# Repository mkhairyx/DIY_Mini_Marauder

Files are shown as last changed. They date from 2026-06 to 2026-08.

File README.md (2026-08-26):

# DIY_Mini_Marauder

This is an open source version of [JustCallMeKoko's](github.com/justcallmekoko) marauder mini with better documentation and tutorials on how flash the device after making it. <br>
<br>

The reason I made this repository is becaused I have always wanted to have my own marauder mini but it was unavailble and there was no Schematics to be found for it. <br>
Only thing I was able to find was the PCB and the Case for it. I reverse engineered the PCB to have a useful schematic that anyone can use to make their own PCB and maybe make changes to it. <br>

## The Poster
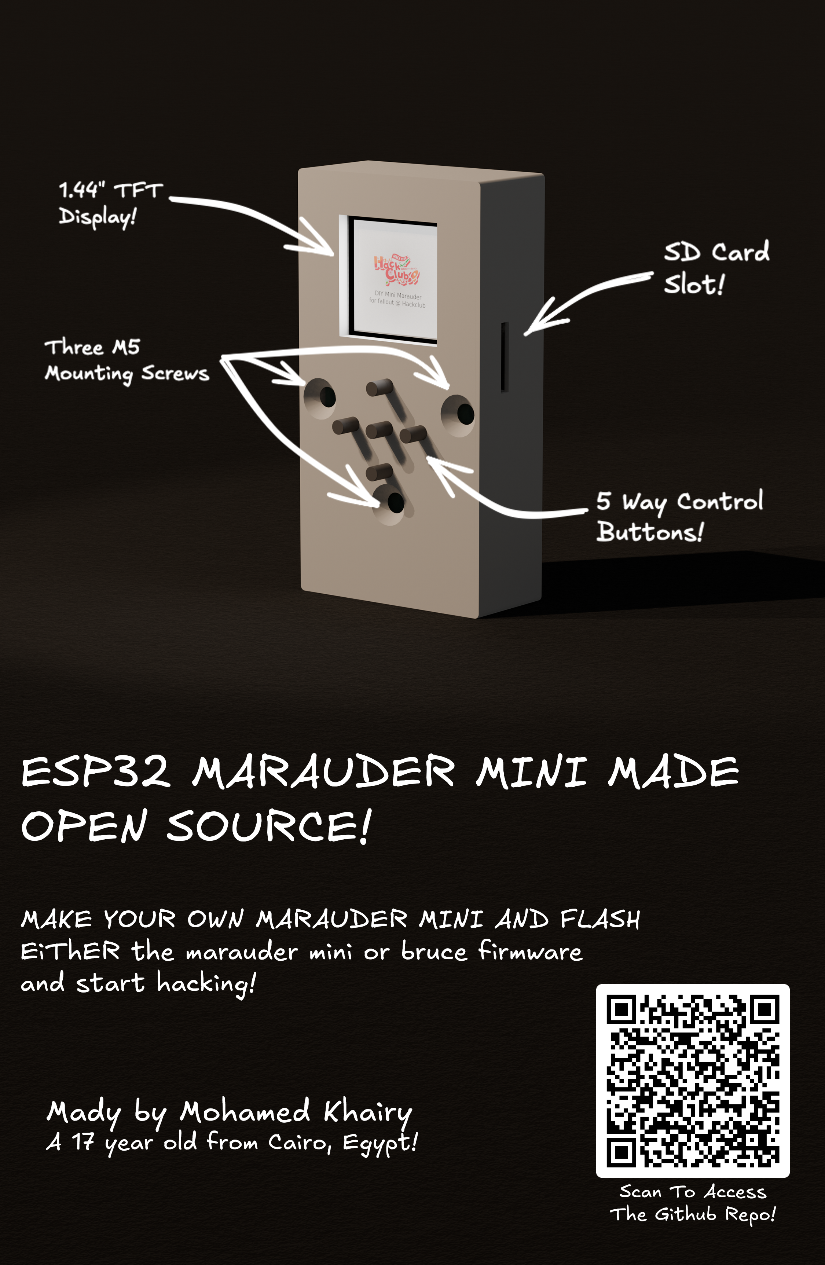
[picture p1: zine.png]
Poster


## The Design
### The PCB
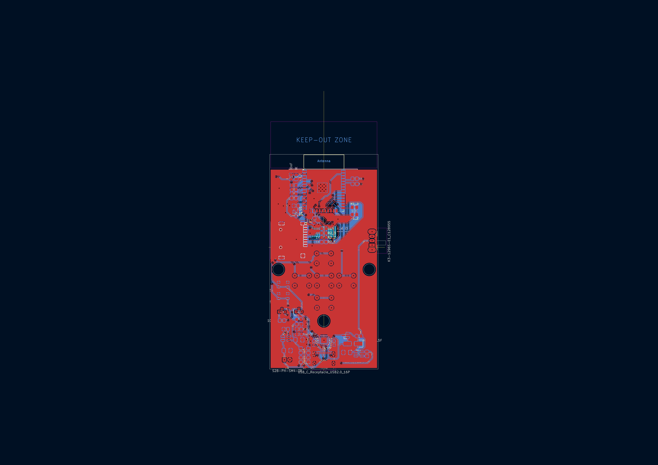
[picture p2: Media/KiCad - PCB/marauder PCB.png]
PCB

### The Schematics
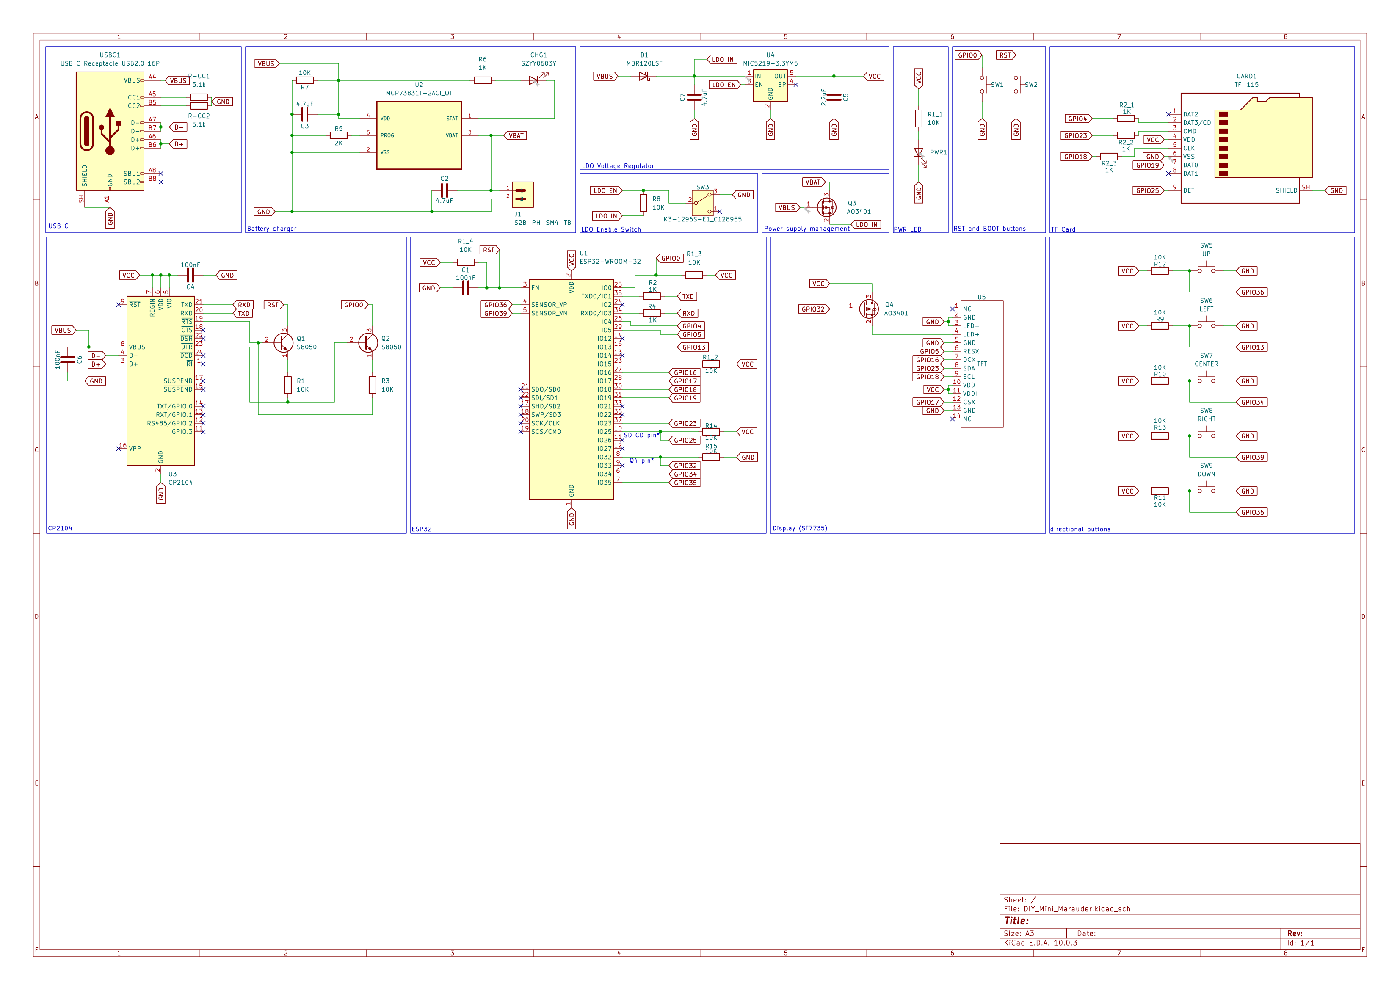
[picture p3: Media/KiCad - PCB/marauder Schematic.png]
Schematics

### The Enclosure Case 
With the device inside:
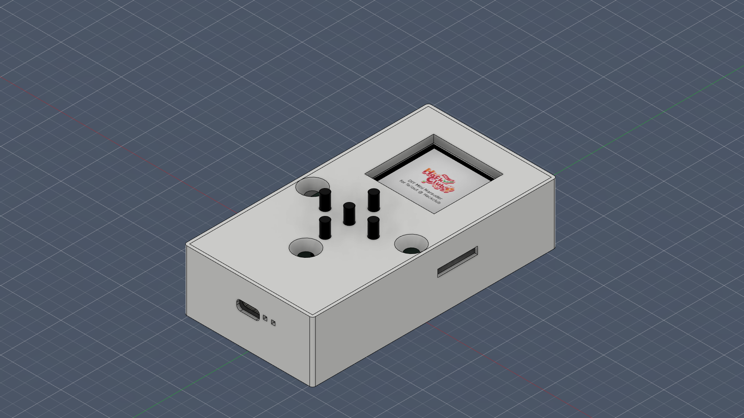
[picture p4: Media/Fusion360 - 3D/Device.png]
Device


Without the device inside:
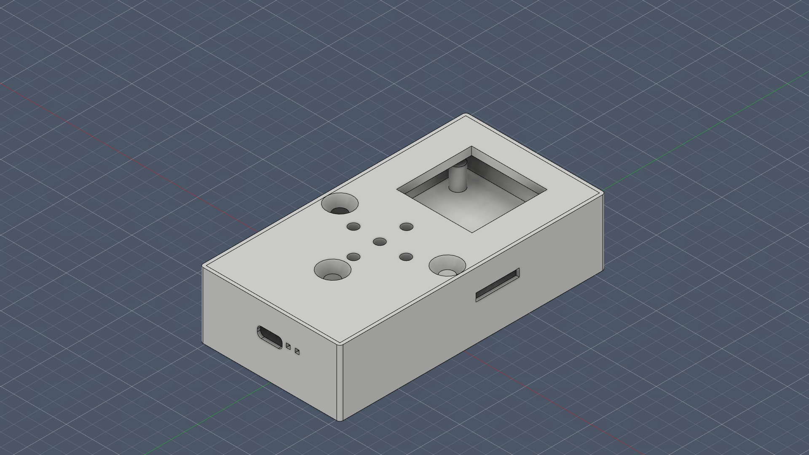
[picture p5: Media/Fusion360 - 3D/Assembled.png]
Assmebled


## Assembly
### Step Files
All of the step files can be downloaded [here](./Step_Files/).

### Disassembly video

https://github.com/user-attachments/assets/7e853b93-fa27-431c-8479-e6c7b8179391

## Firmware
### Fzee flasher (Marauder Mini)
- Visit the [FZEE FLASHER](https://fzeeflasher.com/) website
- Make sure your device is connected to your PC
- Click "Connect" <br>


- Select the Programmer chip for your device (which would be CP2104 if you used the schematics/PCB in this repository) <br>


- If you used the schematics/PCB provided in this repository, then you can skip this step. <br>
As soon as you see this screen, hold down the BOOT button on your device as the flasher will automatically reset the device and it will go into the boatloader mode <br>


- Select "ESP32 Marauder Mini Device" <br>


- Select the latest version <br>


- Select "Marauder" as the firmware <br>


- Erase the device first to make sure that it's not affected by any previously installed firmwares <br>


- Click "Program" <br>


- It will take arround 10 seconds to flash the firmware.  <br>
  After those 10 seconds, you should see this screen which indicates that you succesfully flashed the device with the new firmware: <br>
  

### Bruce (Bruce's Firmware)
- Visit [Bruce's Web Firmware Flasher](https://bruce.computer/flasher) 
- Select whatever release you want (it's recommended to select the latest release)
 
 
- Select "Custom Boards"


- Select "Marauder Mini"


- Select "Connect to Device"


- Select the Programmer chip for your device (which would be CP2104 if you used the schematics/PCB in this repository)


- Select "Instal Marauder-Mini"


- Then make sure to have the "Erase device" option enabled then click next


- Confirm the instalation


- If you used the schematics/PCB provided in this repository, then you can skip this step. <br>
As soon as you see this screen, make sure to put your device into the bootloader mode by holding the BOOT button down, pressing the RST button, and then after 2 seconds release the BOOT button.


- It will take around 2 minutes to upload the firmware. <br>
After those 2 minutes, you should see this screen which indicates that you had a succesful instalation:


## Buttons and leds
### The two LEDs
Next to the USB-C port there are 2 LEDs: <br>
- The white one indicates wether the device is powered or not. <br>
- The blue one indicates wether the device is recieved power from the USB-C port or not (which is used to charge the battery).

### The two buttons on the back of the device and their functions
- The Upper button is used to put the ESP32 into the bootloader mode (AKA. the BOOT button). <br>
- The lower button is used to reset the device (AKA. the RST button).<br>

### The side switch
- The side switch is used to power the device ON or OFF.

## BOM
### BOM table (components only)
|Name |Value |Link |Cost (EGP) per one|Cost (USD)|Total Cost (EGP) |Total Cost (USD)|Qty of packages|Description |quantiy per pack|
|---|---|---|---|---|---|---|---|---|---|
|Capacitor |100nF |https://lampatronics.com/product/smd-multilayer-ceramic-capacitor-0805-2012-104-100nf-50v-1pcs-2 | EGP 1.00 | $0.02 | EGP 3.00 | $0.06 |3 | |1 |
|Capacitor |4.7uF |https://lampatronics.com/product/smd-multilayer-ceramic-capacitor-1206-4-7uf-16v-1pcs | EGP 1.50 | $0.03 | EGP 4.50 | $0.09 |3 | |1 |
|Capacitor |2.2uF |https://lampatronics.com/product/smd-multilayer-ceramic-capacitor-0805-2-2uf-50v-1pcs | EGP 1.00 | $0.02 | EGP 1.00 | $0.02 |1 | |1 |
|SD Card slot |TF-115 |https://lampatronics.com/product/push-push-type-tf-micro-sd-card-socket-adapter-automatic-pcb-connector | EGP 8.00 | $0.15 | EGP 8.00 | $0.15 |1 | |1 |
|Charging LED |SZYY0603Y |https://lampatronics.com/product/smd-led-0805-blue-10pcs | EGP 8.00 | $0.15 | EGP 8.00 | $0.15 |1 |Charge LED (RED) |10 |
|Power LED |SZYY0603Y |https://lampatronics.com/product/smd-led-0805-white-10pcs | EGP 8.00 | $0.15 | EGP 8.00 | $0.15 |1 |Power LED (White) |10 |
|Schottky Diode |MBR120LSF (alt: 1N5819 SS14)|https://uge-one.com/product/smd-schottky-diode-1n5819-ss14-1a-40v-sma-package/ | EGP 2.50 | $0.05 | EGP 2.50 | $0.05 |1 |Schottky |1 |
|JST Connector |S2B-PH-SM4-TB |https://uge-one.com/product/jst-connector-male-polarized-xh2-54-2p/ | EGP 1.14 | $0.02 | EGP 1.14 | $0.02 |1 |JST connector |1 |
|BOOT and RESET transistors |S8050 |https://lampatronics.com/product/s8050-transistor-40v-0-5a-npn | EGP 0.50 | $0.01 | EGP 1.00 | $0.02 |2 |RST&BOOT transistors |1 |
|Power management and TFT LED PWM|AO3401 |https://uge-one.com/product/ao3401-sot23-general-purpose-p-channel-mosfet-smd-transistor-sot-23/ | EGP 3.00 | $0.06 | EGP 6.00 | $0.12 |2 |Power manage, TFT LED|1 |
|Resistor |5.1k |https://uge-one.com/product/smd-chip-resistor-size-0603-5-1k-ohm/ | EGP 0.50 | $0.01 | EGP 1.00 | $0.02 |2 |USB-C resistors 5.1k |1 |
|Resistor |10K |https://lampatronics.com/product/smd-resistor-10kohm-103-0805-10pcs | EGP 2.00 | $0.04 | EGP 4.00 | $0.08 |2 | |10 |
|Resistor |1K |https://lampatronics.com/product/smd-resistor-1kohm-102-0805-10pcs | EGP 2.00 | $0.04 | EGP 2.00 | $0.04 |1 | |10 |
|Prog Resistor |2K |https://lampatronics.com/product/smd-resistor-2kohm-202-0805-10pcs | EGP 2.00 | $0.04 | EGP 2.00 | $0.04 |1 | |10 |
|RST and BOOT buttons |SW_Omron_B3FS |https://lampatronics.com/product/smd-push-button-3425mm-tactile-tact-micro-switch-momentary-4pin | EGP 3.00 | $0.06 | EGP 6.00 | $0.12 |2 | |1 |
|LDO Enable Switch |K3-1296S-E1_C128955 |https://uge-one.com/product/horizontal-small-slide-toggle-switch-spdt-3pin-2mm-pin-spacing-sk12d02vg7/ | EGP 4.00 | $0.08 | EGP 4.00 | $0.08 |1 |Power slide switch |1 |
|directional buttons | |https://lampatronics.com/product/push-button-4pin-long-6x6x13mm | EGP 1.50 | $0.03 | EGP 7.50 | $0.14 |5 |Directional switch |1 |
|MCU |ESP32-WROOM-32 |https://uge-one.com/product/espressif-esp32-wroom-32-dual-core-wi-fi-bluetooth-iot-module/ | EGP 290.00 | $5.58 | EGP 290.00 | $5.58 |1 |MCU |1 |
|Battery charger |MCP73831T-2ACI_OT |[Long Aliexpress link](https://ar.aliexpress.com/item/32844180448.html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)| N/A | $4.28 | N/A | $4.28 |1 |Battery Charger |10 |
|Programmer |CP2104 |[Long Aliexpress link](https://ar.aliexpress.com/item/1005012309258723.html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) | N/A | $1.97 | N/A | $1.97 |1 |USB to TTL chip |1 |
|LDO Regulator |MIC5219-3.3YM5 |[Long Aliexpress link](https://ar.aliexpress.com/item/1005006130724980.html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) | N/A | $4.23 | N/A | $4.23 |1 |LDO regulator |10 |
|Display |TFT_1.44 |[Long Aliexpress link](https://ar.aliexpress.com/item/1005001598020071.html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) | N/A | $2.16 | N/A | $2.16 |1 | |1 |
|USB-C |USB_C_Receptacle_USB2.0_16P |https://www.ram-e-shop.com/shop/usb9-c-type-pcb-usb-connector-on-pcb-c-type-type-female-16-pin-sku-usb9-8125 | EGP 5.00 | $0.10 | EGP 5.00 | $0.10 |1 | |1 |
|Battery |700 mah |https://lampatronics.com/product/battery-polymer-3-7v-700mah-li-ion-single-cell-35x20x5mm-502035 | EGP 135.00 | $2.60 | EGP 135.00 | $2.60 |1 | |1 |
|M5 Screws |M5*16mm |https://store.fut-electronics.com/products/screw-m5x16mm-hexagonal-head?_pos=15&_sid=376b1bf88&_ss=r | EGP 2.00 | $0.04 | EGP 2.00 | $0.04 |1 | |1 |
| | | | | | | | | | |
| | | | | | EGP 501.64 | $22.29 | | | |
| | | | | | (Stuff from aliexpress not included here) | | | | |

### Orders from different manufacturers
#### In Egypt
[Nori](norisolutions.com) (PCB only): $19.09 <br>

<br>

 [Metanoia](metanoia-eg.com) (Case only): $5.96 <br>
 
<br>

#### Out of Egypt
[JLCPCB](https://jlcpcb.com/) (both PCB and Case): $31.15 <br>


<br>
<br>
<br>

<h1 align="center"> DISCLAIMER </h1>

<h4 align="center">Please note that the use of this tool is entirely at your own risk. It is intended strictly for educational purposes and should not be used for any illegal or unethical activities. Jamming is illegal and can get you in big trouble!</h4>
<h4 align="center">I'm not responsible for your actions! </h4>

<br>

> The firmware is designed by [JustCallMeKoko](github.com/justcallmekoko). <br>
The PCB that was reverse engineered for the making of [DIY Mini Marauder](https://github.com/mkhairyx/DIY_Mini_Marauder) is designed by [JustCallMeKoko](https://github.com/justcallmekoko).<br>
This repo and all of it's contents were Designed by [@mkhairyx](https://github.com/mkhairyx).<br>
Supported by [Fallout](https://fallout.hackclub.com/) and [Hack Club](https://hackclub.com).<br>

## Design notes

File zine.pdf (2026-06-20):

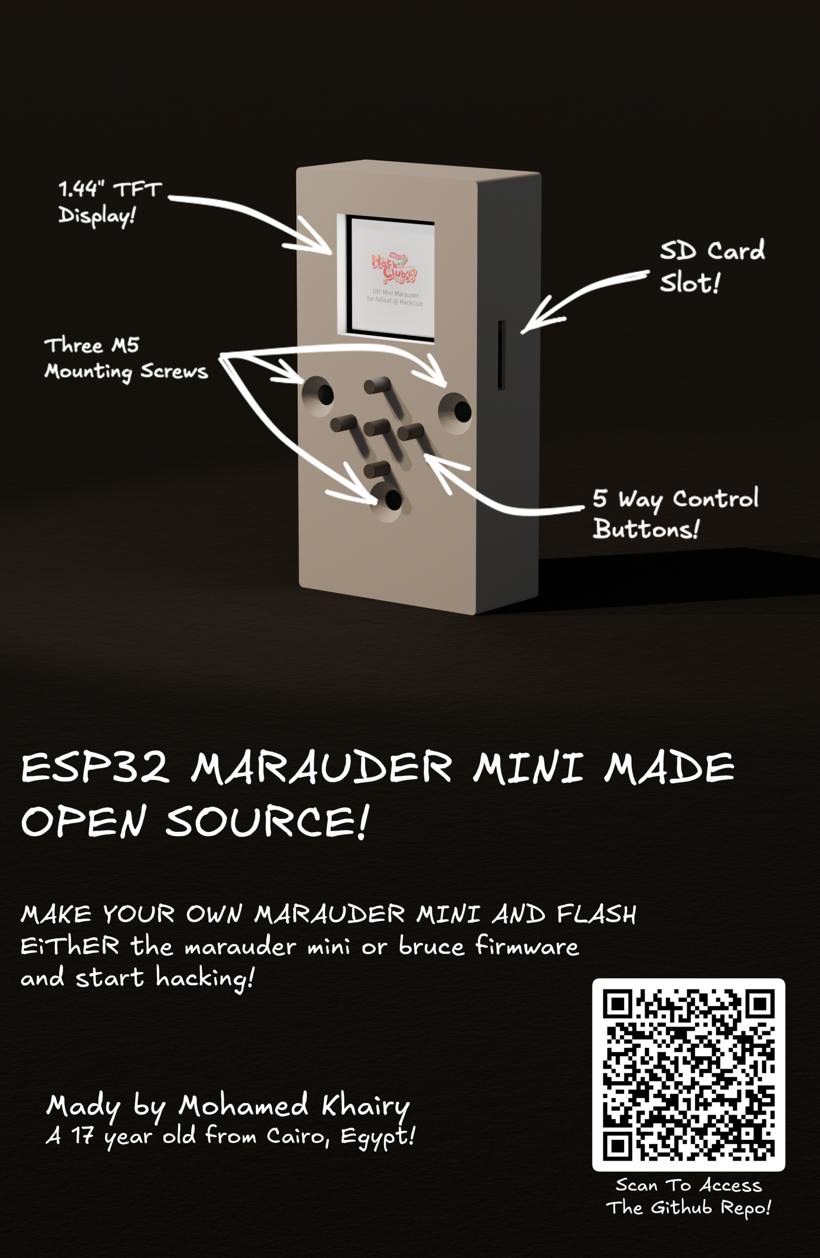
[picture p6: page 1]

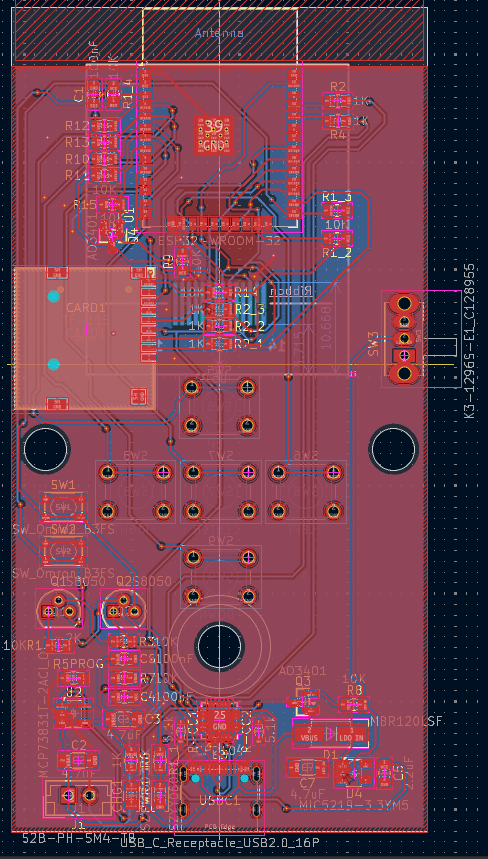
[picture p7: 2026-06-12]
Media/KiCad - PCB/screenshot_pcb.png

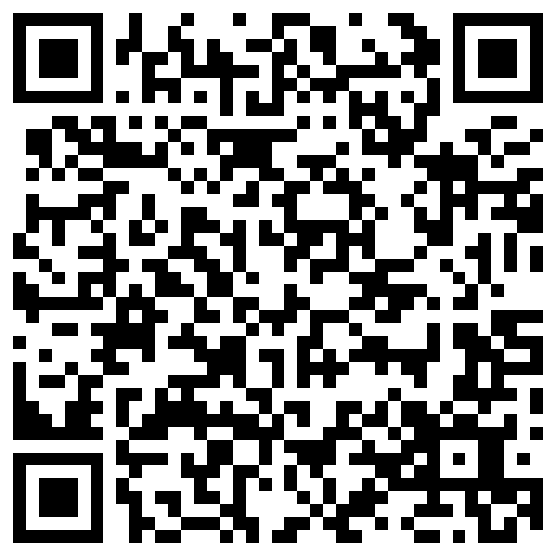
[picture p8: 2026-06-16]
QR.png

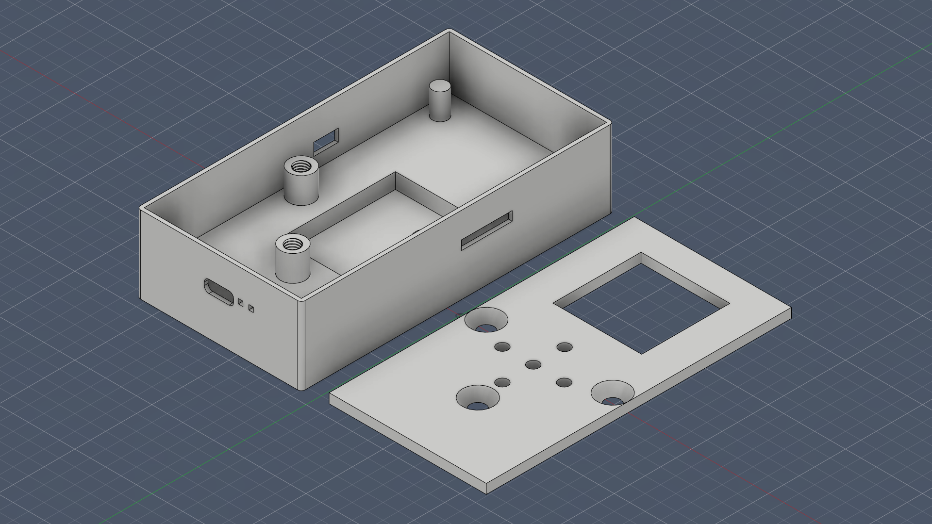
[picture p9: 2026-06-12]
Media/Fusion360 - 3D/Case.png

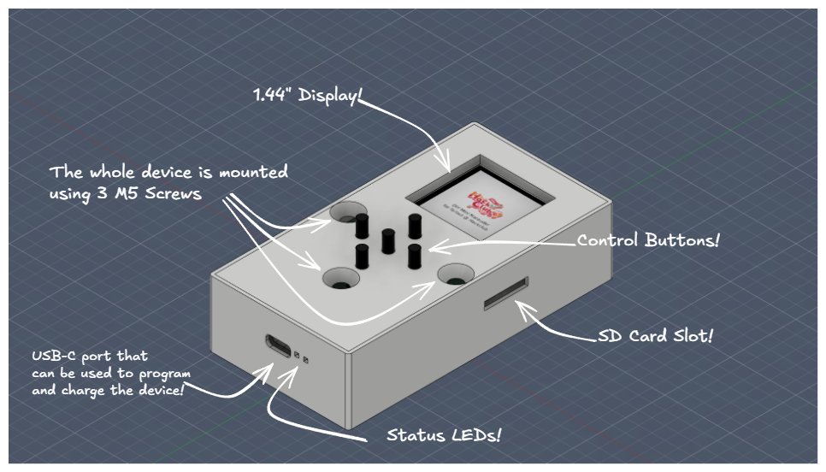
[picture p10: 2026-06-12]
Media/Excalidraw/Explaining.png

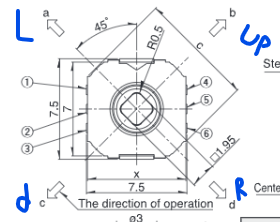
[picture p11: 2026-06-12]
source/KiCad - PCB/DIY_Mini_Marauder/reverse resources/BUTTONS.png

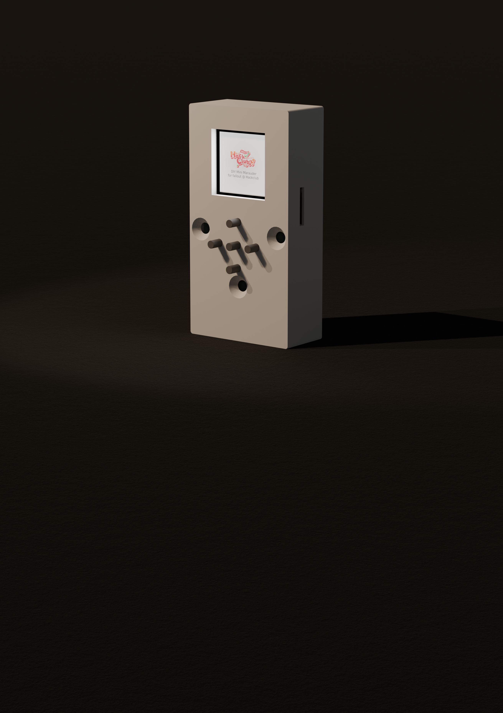
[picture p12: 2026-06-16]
source/Blender - Renders/Render_sun.png

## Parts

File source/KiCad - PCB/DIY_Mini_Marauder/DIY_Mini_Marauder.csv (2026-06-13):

Reference | Qty | Value
C1,C4,C6 | 3 | 100nF
C2,C3,C7 | 3 | 4.7uF
C5 | 1 | 2.2uF
CARD1 | 1 | TF-115
CHG1 | 1 | SZYY0603Y
D1 | 1 | MBR120LSF
J1 | 1 | S2B-PH-SM4-TB
PWR1 | 1 | SZYY0603Y
Q1,Q2 | 2 | S8050
Q3,Q4 | 2 | AO3401
R-CC1,R-CC2 | 2 | 5.1k
R1,R3,R7,R8,R9,R10,R11,R12,R13,R14,R15 | 11 | 10K
R1_1,R1_2,R1_3,R1_4 | 4 | 10K
R2,R4,R6 | 3 | 1K
R2_1,R2_2,R2_3 | 3 | 1K
R5 | 1 | 2K
SW1,SW2 | 2 | SW_Omron_B3FS
SW3 | 1 | K3-1296S-E1_C128955
SW5 | 1 | UP
SW6 | 1 | LEFT
SW7 | 1 | CENTER
SW8 | 1 | RIGHT
SW9 | 1 | DOWN
U1 | 1 | ESP32-WROOM-32
U2 | 1 | MCP73831T-2ACI_OT
U3 | 1 | CP2104
U4 | 1 | MIC5219-3.3YM5
U5 | 1 | TFT
USBC1 | 1 | USB_C_Receptacle_USB2.0_16P

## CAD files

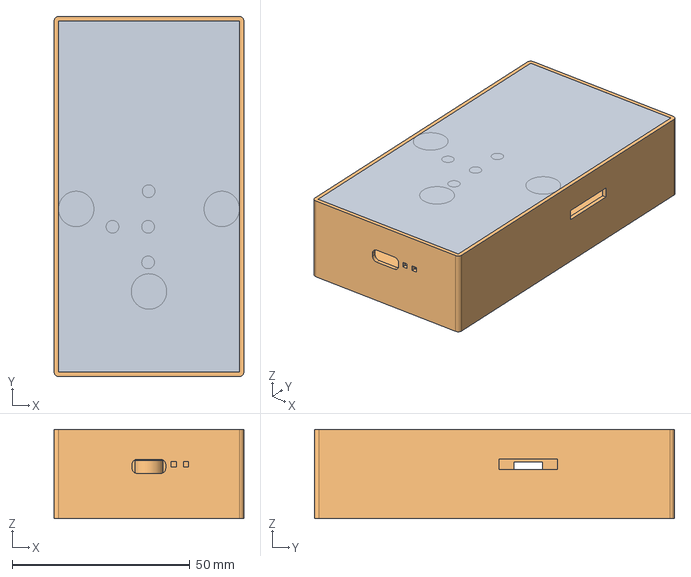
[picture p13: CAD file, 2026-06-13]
Step_Files/Assembled/Assembled.step
53.4 x 101.4 x 25.1 mm
Front cover
Back cover

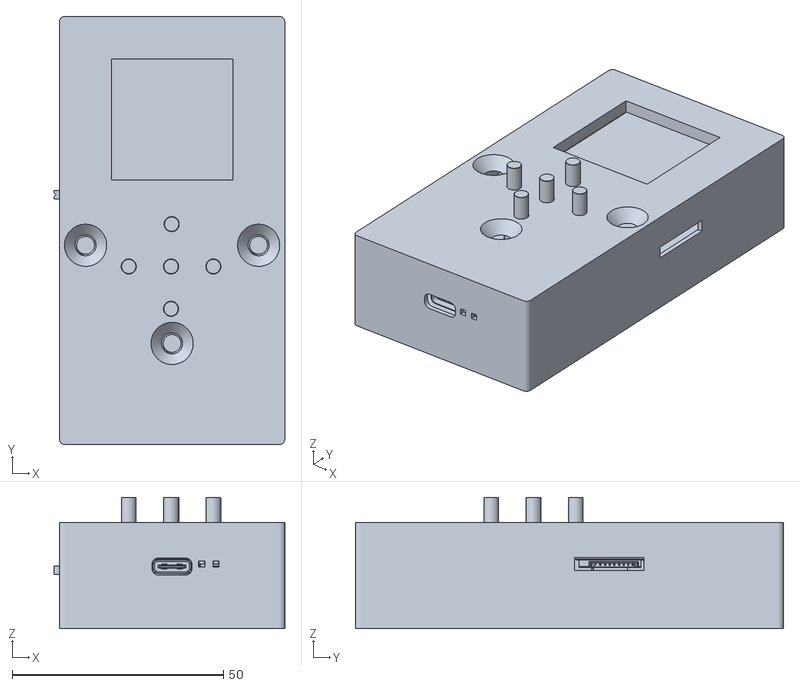
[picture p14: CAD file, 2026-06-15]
source/Blender - Renders/Device/Device.stl
54.6 x 101.4 x 31.1

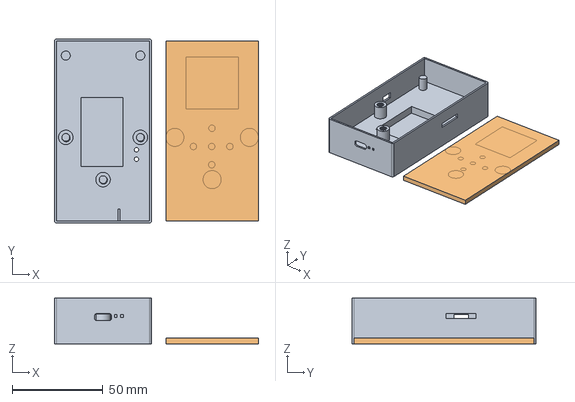
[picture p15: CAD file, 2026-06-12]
source/Fusion360 - 3D/Case.step
112.2 x 101.4 x 25.1 mm

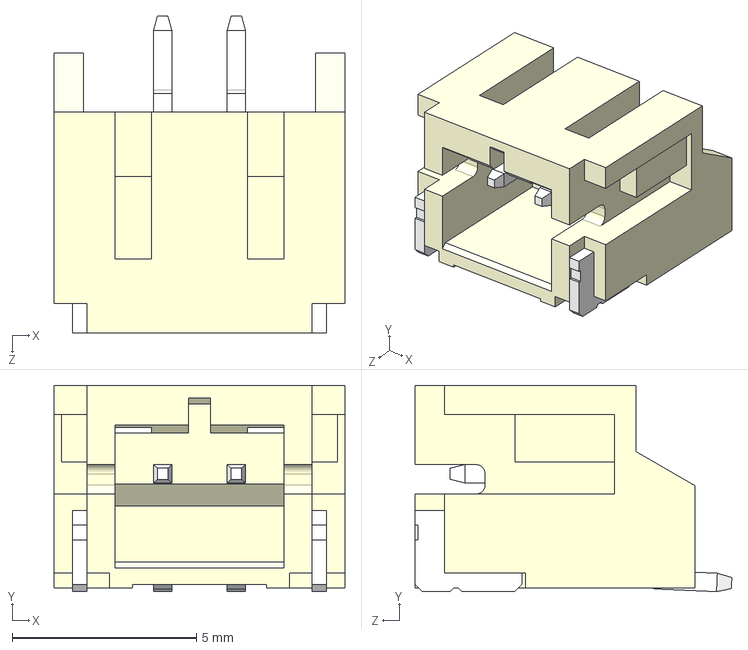
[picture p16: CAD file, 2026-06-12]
source/KiCad - PCB/DIY_Mini_Marauder/Footprints/PCB Footprint/S2B-PH-SM4-TB/S2B-PH-SM4-TB.step
7.90 x 5.60 x 8.60 mm

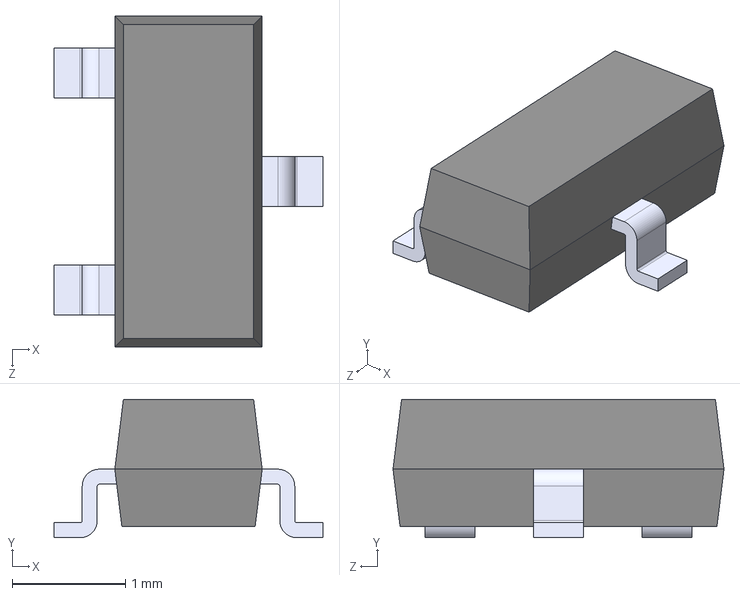
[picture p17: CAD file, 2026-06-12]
source/KiCad - PCB/DIY_Mini_Marauder/Footprints/PCB Footprint/SI2305-TP/SI2305-TP.step
2.37 x 1.22 x 2.92 mm

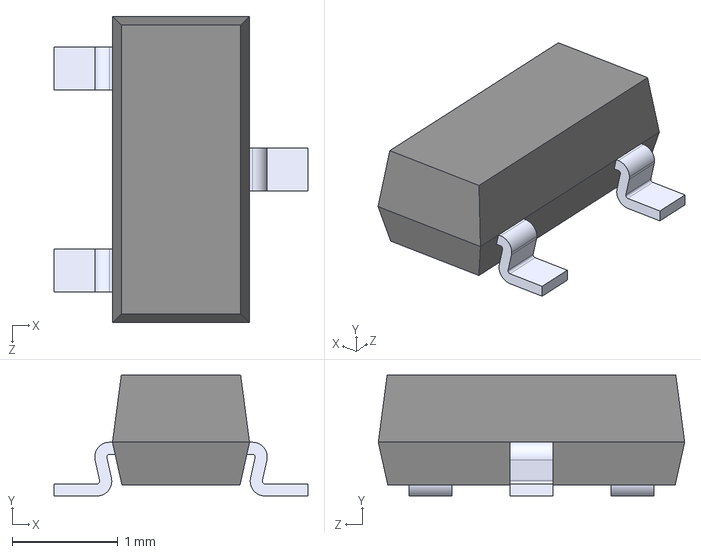
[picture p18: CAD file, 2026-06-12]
source/KiCad - PCB/DIY_Mini_Marauder/Footprints/PCB Footprint/SS8050-G/SS8050-G.step
2.40 x 1.14 x 2.90 mm

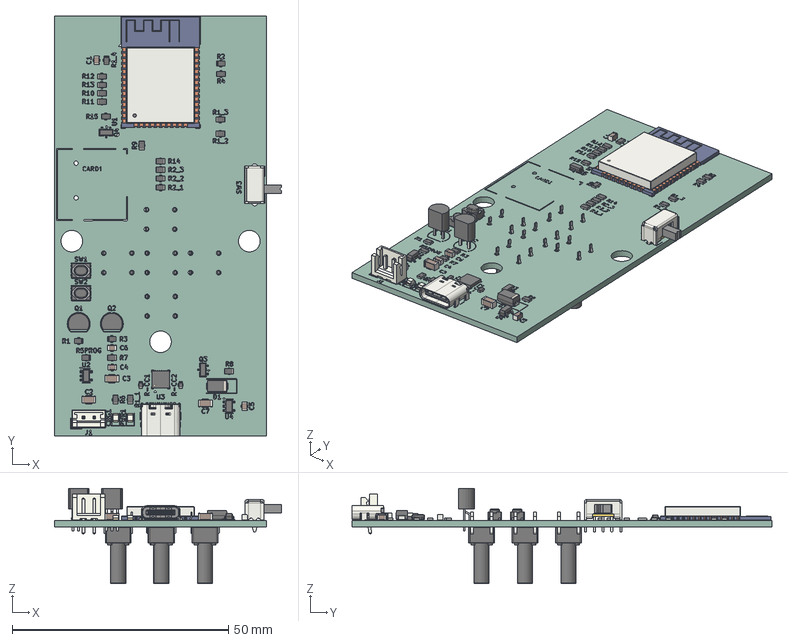
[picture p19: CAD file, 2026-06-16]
source/KiCad - PCB/DIY_Mini_Marauder/MoonLamp_PCB.step
52.4 x 97.0 x 22.0 mm
R_0805_2012Metric x 22
TO-92_Narrow x 2
C_1206_3216Metric x 3
C_0805_2012Metric x 4
JST_B2B_EH_A
SOT-23 x 2
QFN-24-1EP_4x4mm_Pitch0.5mm
ESP32-WROOM-32
SOT-23-5 x 2
R_0603_1608Metric x 2
SW_Slide_SPDT_Angled_CK_OS102011MA1Q
D_SMA
SW_SPST_PTS810 x 2
LED_0805_2012Metric x 2
USB_C_Receptacle_16P_TopMnt_Horizontal_GCT_USB4105-xx-A
SW_PUSH_6mm_h13mm x 5
DIY_Mini_Marauder_silkscreen x 2
DIY_Mini_Marauder_PCB

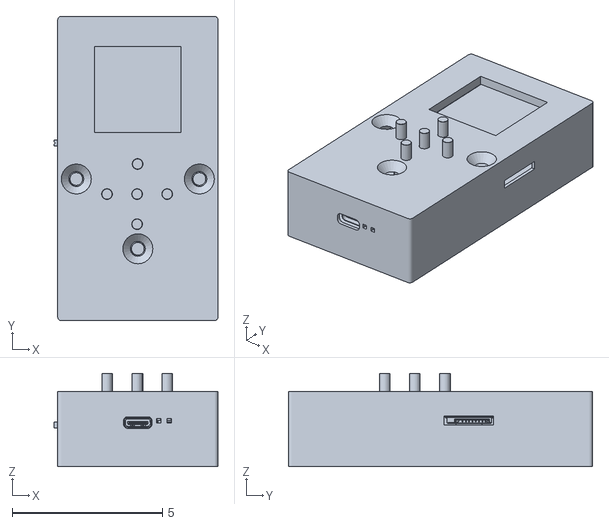
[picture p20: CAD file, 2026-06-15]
source/Blender - Renders/Device/Marauder_PCB_Show.obj
5.46 x 10.1 x 3.11

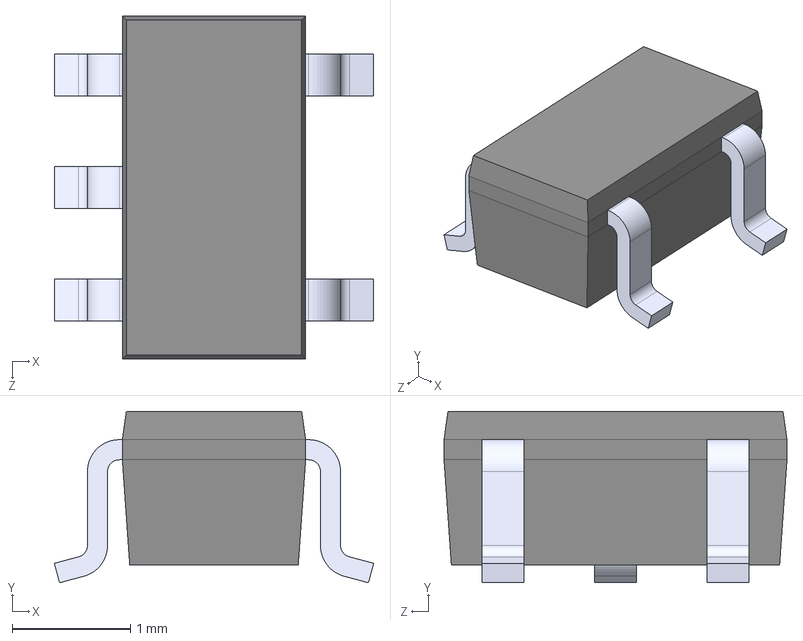
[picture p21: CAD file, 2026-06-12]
source/KiCad - PCB/DIY_Mini_Marauder/Footprints/PCB Footprint/MCP73831T-2ACI_OT/MCP73831T-2ACI_OT.step
2.70 x 1.45 x 2.90 mm

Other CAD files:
Step_Files/Case/Case.step
source/Blender - Renders/Render.blend
source/Fusion360 - 3D/Case.f3z
source/Fusion360 - 3D/Showcase.f3z

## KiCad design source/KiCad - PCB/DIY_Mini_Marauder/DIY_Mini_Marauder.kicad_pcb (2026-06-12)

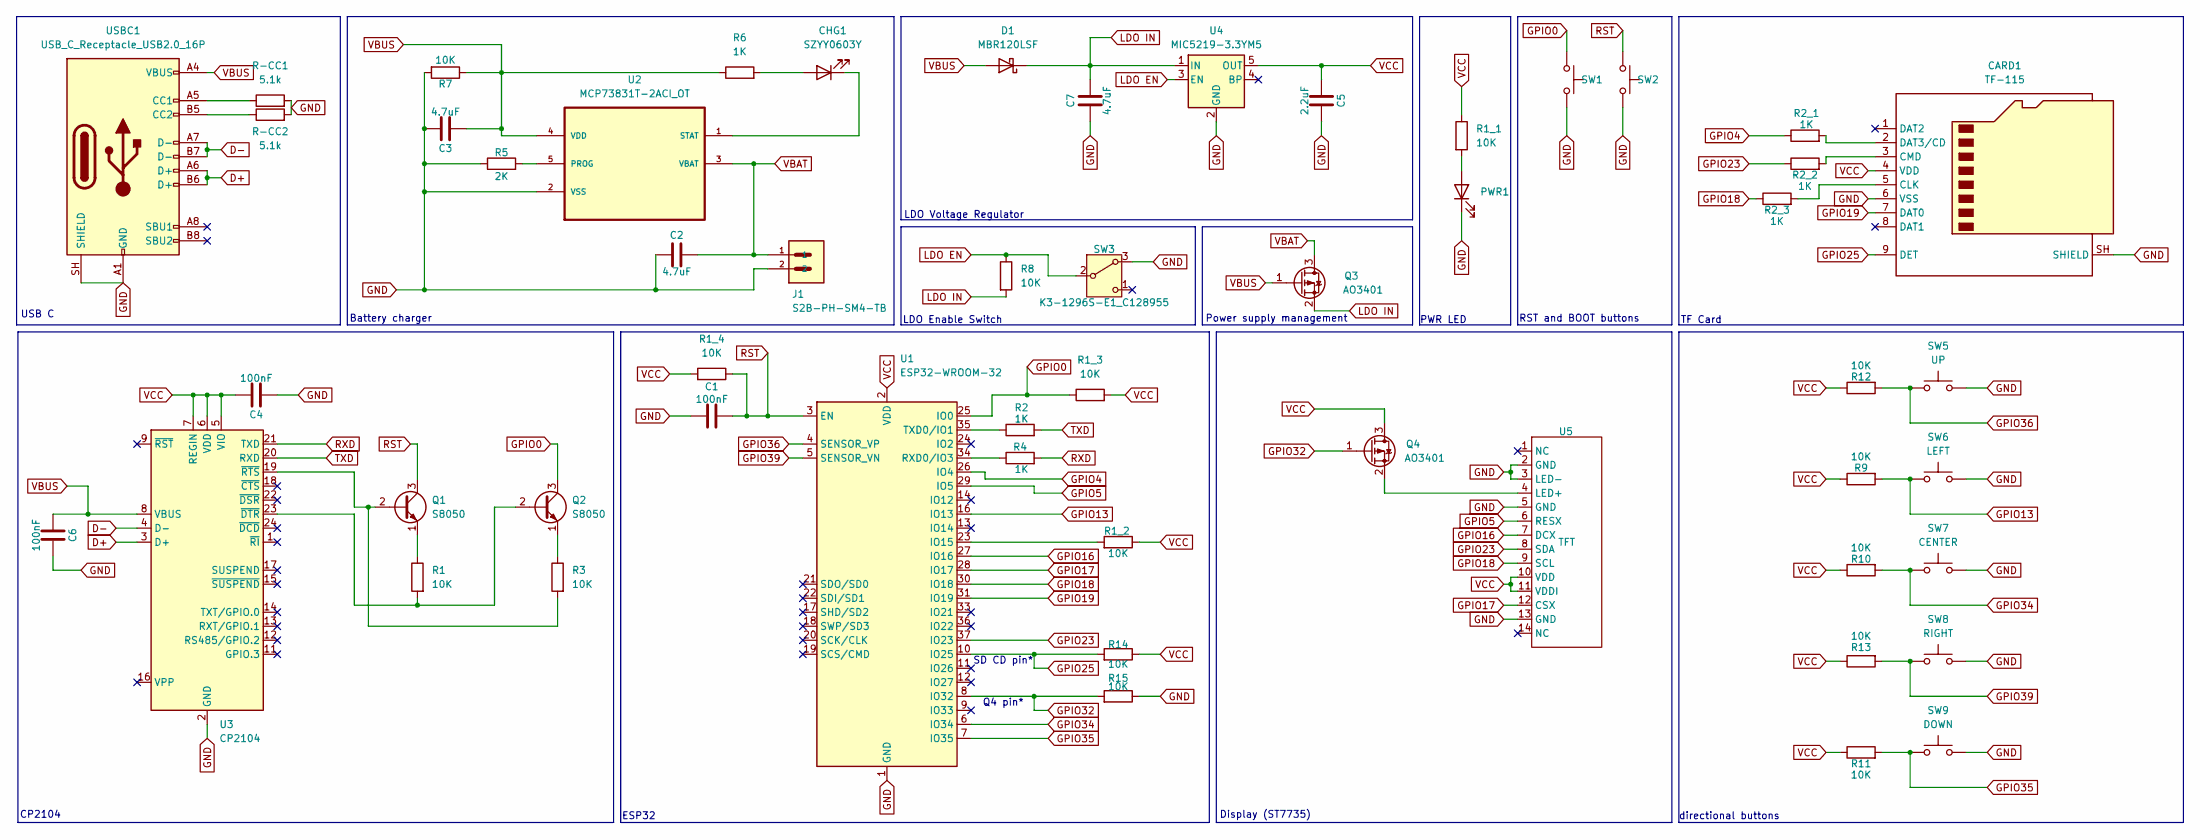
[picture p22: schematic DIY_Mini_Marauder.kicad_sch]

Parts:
C1, C4, C6: 100nF; C_0805_2012Metric_Pad1.18x1.45mm_HandSolder
C2, C3, C7: 4.7uF; C_1206_3216Metric_Pad1.33x1.80mm_HandSolder
C5: 2.2uF; C_0805_2012Metric_Pad1.18x1.45mm_HandSolder
CARD1: TF-115
CHG1: SZYY0603Y; LED_0805_2012Metric_Pad1.15x1.40mm_HandSolder
D1: MBR120LSF; D_SMA_Handsoldering
J1: S2B-PH-SM4-TB; JST_EH_B2B-EH-A_1x02_P2.50mm_Vertical
PWR1: SZYY0603Y; LED_0805_2012Metric_Pad1.15x1.40mm_HandSolder
Q1, Q2: S8050; TO-92
Q3, Q4: AO3401; SOT-23
R1, R1_1, R1_2, R1_3, R1_4, R3, R7, R8, R9, R10, R11, R12, R13, R14, R15: 10K; R_0805_2012Metric_Pad1.20x1.40mm_HandSolder
R2, R2_1, R2_2, R2_3, R4, R6: 1K; R_0805_2012Metric_Pad1.20x1.40mm_HandSolder
R5: 2K; R_0805_2012Metric_Pad1.20x1.40mm_HandSolder
R-CC1, R-CC2: 5.1k; R_0603_1608Metric_Pad0.98x0.95mm_HandSolder
SW1, SW2: SW_Omron_B3FS; SW_SPST_PTS810
SW3: K3-1296S-E1_C128955; SW_Slide_SPDT_Angled_CK_OS102011MA1Q
SW5: UP; SW_PUSH_6mm_H13mm
SW6: LEFT; SW_PUSH_6mm_H13mm
SW7: CENTER; SW_PUSH_6mm_H13mm
SW8: RIGHT; SW_PUSH_6mm_H13mm
SW9: DOWN; SW_PUSH_6mm_H13mm
U1: ESP32-WROOM-32
U2: MCP73831T-2ACI_OT; SOT-23-5_HandSoldering; MPN MCP73831T-2ACI/OT
U3: CP2104; QFN-24-1EP_4x4mm_P0.5mm_EP2.6x2.6mm
U4: MIC5219-3.3YM5; SOT-23-5_HandSoldering
U5: TFT; ST7735_TFT_14P
USBC1: USB_C_Receptacle_USB2.0_16P; USB_C_Receptacle_GCT_USB4105-xx-A_16P_TopMnt_Horizontal

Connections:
D+: U3.3 (D+), USBC1.A6 (D+), USBC1.B6 (D+)
D-: U3.4 (D-), USBC1.A7 (D-), USBC1.B7 (D-)
GND: C1.1, C2.1, C3.2, C4.1, C5.2, C6.2, C7.1, CARD1.6 (VSS), CARD1.SH (SHIELD), J1.2, PWR1.1 (K), R5.1, R7.2, R15.1, R-CC1.2, R-CC2.2, SW1.1, SW2.1, SW3.3 (A), SW5.2, SW6.2, SW7.2, SW8.2, SW9.2, U1.1 (GND), U1.15 (GND), U1.38 (GND), U1.39 (GND), U2.2 (VSS), U3.2 (GND), U3.25 (GND), U4.2 (GND), U5.2 (GND), U5.3 (LED-), U5.5 (GND), U5.13 (GND), USBC1.A1 (GND), USBC1.A12 (GND), USBC1.B1 (GND), USBC1.B12 (GND), USBC1.SH (SHIELD)
GPIO0: Q2.3 (C), R1_3.1, SW1.2, U1.25 (IO0)
GPIO4: R2_1.1, U1.26 (IO4)
GPIO5: U1.29 (IO5), U5.6 (RESX)
GPIO13: R9.2, SW6.1, U1.16 (IO13)
GPIO16: U1.27 (IO16), U5.7 (DCX)
GPIO17: U1.28 (IO17), U5.12 (CSX)
GPIO18: R2_3.1, U1.30 (IO18), U5.9 (SCL)
GPIO19: CARD1.7 (DAT0), U1.31 (IO19)
GPIO23: R2_2.1, U1.37 (IO23), U5.8 (SDA)
GPIO25: CARD1.9 (DET), R14.2, U1.10 (IO25)
GPIO32: Q4.1 (G), R15.2, U1.8 (IO32)
GPIO34: R10.2, SW7.1, U1.6 (IO34)
GPIO35: R11.2, SW9.1, U1.7 (IO35)
GPIO36: R12.2, SW5.1, U1.4 (SENSOR_VP)
GPIO39: R13.2, SW8.1, U1.5 (SENSOR_VN)
LDO EN: R8.1, SW3.2 (B), U4.3 (EN)
LDO IN: C7.2, D1.1 (K), Q3.2 (S), R8.2, U4.1 (IN)
unnamed: CARD1.5 (CLK), R2_3.2
unnamed: CARD1.3 (CMD), R2_2.2
unnamed: CARD1.2 (DAT3/CD), R2_1.2
unnamed: CHG1.2 (A), R6.2
unnamed: CHG1.1 (K), U2.1 (STAT)
unnamed: PWR1.2 (A), R1_1.2
unnamed: Q1.2 (B), R3.2, U3.19 (~RTS)
unnamed: Q1.1 (E), R1.1
unnamed: Q2.2 (B), R1.2, U3.23 (~DTR)
unnamed: Q2.1 (E), R3.1
unnamed: Q4.2 (S), U5.4 (LED+)
unnamed: R1_2.2, U1.23 (IO15)
unnamed: R4.1, U1.34 (RXD0/IO3)
unnamed: R2.1, U1.35 (TXD0/IO1)
unnamed: R5.2, U2.5 (PROG)
unnamed: R-CC1.1, USBC1.A5 (CC1)
unnamed: R-CC2.1, USBC1.B5 (CC2)
RST: C1.2, Q1.3 (C), R1_4.1, SW2.2, U1.3 (EN)
RXD: R4.2, U3.21 (TXD)
TXD: R2.2, U3.20 (RXD)
VBAT: C2.2, J1.1, Q3.3 (D), U2.3 (VBAT)
VBUS: C3.1, C6.1, D1.2 (A), Q3.1 (G), R6.1, R7.1, U2.4 (VDD), U3.8 (VBUS), USBC1.A4 (VBUS), USBC1.A9 (VBUS), USBC1.B4 (VBUS), USBC1.B9 (VBUS)
VCC: C4.2, C5.1, CARD1.4 (VDD), Q4.3 (D), R1_1.1, R1_2.1, R1_3.2, R1_4.2, R9.1, R10.1, R11.1, R12.1, R13.1, R14.1, U1.2 (VDD), U3.5 (VIO), U3.6 (VDD), U3.7 (REGIN), U4.5 (OUT), U5.10 (VDD), U5.11 (VDDI)

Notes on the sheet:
directional buttons
LDO Enable Switch
SD CD pin*
Power supply management
LDO Voltage Regulator
Q4 pin*
USB C
Battery charger
RST and BOOT buttons
TF Card
PWR LED
ESP32
CP2104
Display (ST7735)

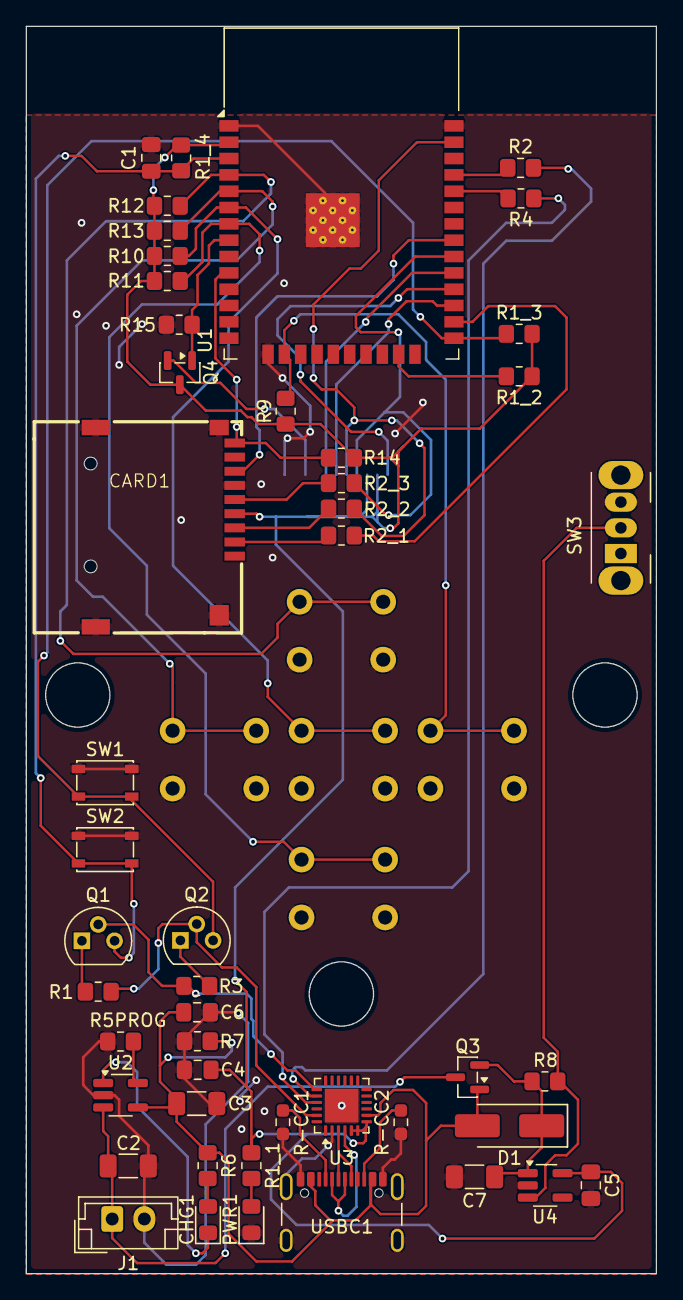
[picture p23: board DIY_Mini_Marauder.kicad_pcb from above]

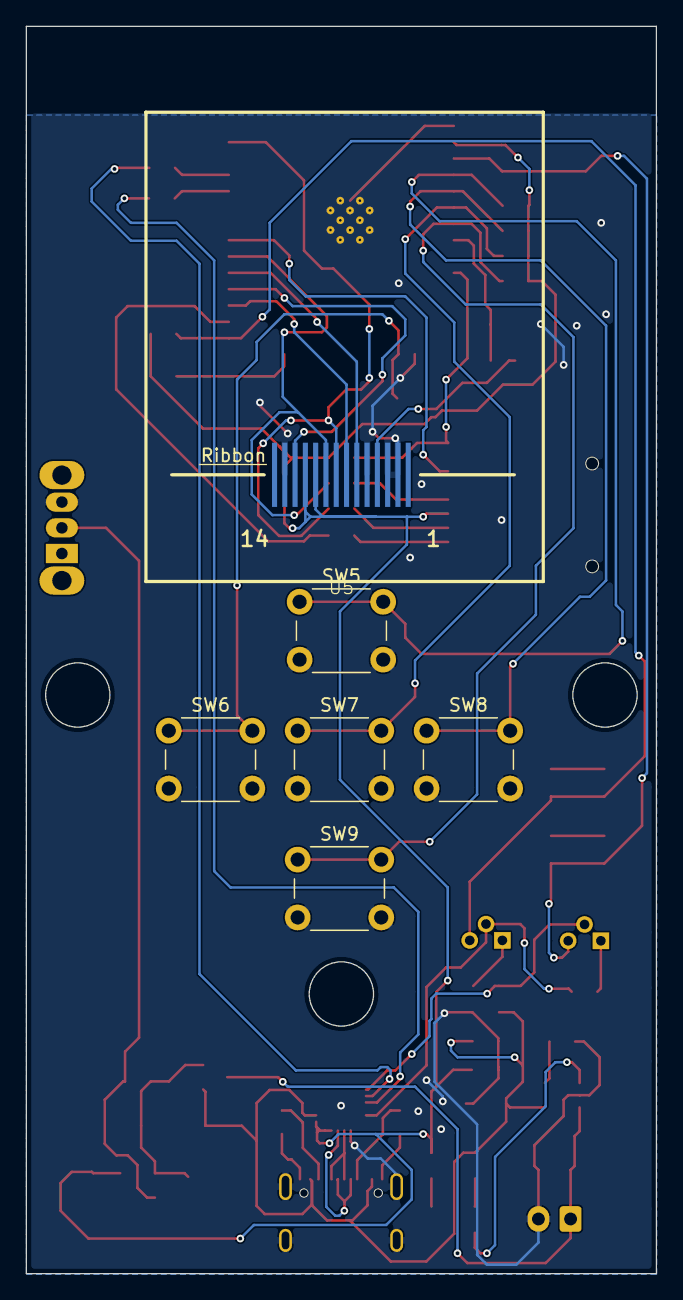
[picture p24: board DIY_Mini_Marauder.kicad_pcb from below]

Board: 2 copper layers, 49.0 x 97.0 mm, 54 parts (6 on the bottom side), 43 nets.

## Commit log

2026-06-12 Uploading the files to git
    [Assembled.step, Case.step, DIY_Mini_Marauder.kicad_pcb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]
2026-06-12 Added BOM
    [BOM.csv]
2026-06-13 uploading files from other device
    [BOM.csv]
2026-06-13 Done most of the readme
    [Assembled.step, BOM.csv, Case.step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]
2026-06-14 Revise README for improved documentation and tutorials
    Updated README to include better documentation and tutorials for flashing the device. Added links and images for assembly and firmware installation.
2026-06-15 Added files for rendering and a rendered picutre
    [Device.stl, Marauder_PCB_Show.obj, Render.blend]
2026-06-15 edited blender files
    [Render.blend]
2026-06-16 Saved changes in blender
    Made the screen brighter
    [Render.blend]
2026-06-16 Edited render and added a new pic
    Added a sun light
    [Render.blend]
2026-06-16 Update README with poster and cost changes
    Added a poster image and updated the cost for the case from Metanoia.
2026-06-16 renamed folders
    [Case.f3z, Case.step, DIY_Mini_Marauder.csv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]
2026-06-20 Revise README for clarity and additional information
    Updated README with project details, assembly instructions, firmware flashing guide, BOM, and manufacturer information.
2026-08-26 Revise README for clarity and additional details
    Updated README.md to enhance documentation and provide better clarity on the project purpose, assembly instructions, firmware flashing, and components.
